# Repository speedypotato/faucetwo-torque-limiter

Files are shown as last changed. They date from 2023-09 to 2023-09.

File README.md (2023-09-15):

# faucetwo-torque-limiter
This work is licensed under a Creative Commons Attribution-NonCommercial-ShareAlike 4.0 International License.

Consumable proprietary rubber dampeners begone!  Uses a tok tleu1-618-5w torque limiter as tensioning just like a valkyrie knob assembly!

Note: This project has been fitted and tested but is still in beta.

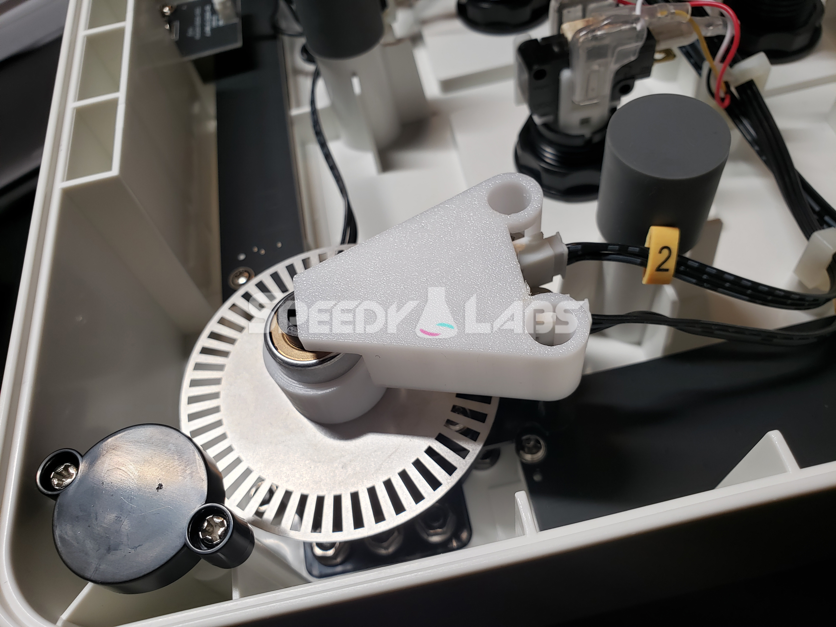
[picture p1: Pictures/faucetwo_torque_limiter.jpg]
Faucetwo Torque Limiter


This mod requires:
- 2x tok tleu1-618-5w
- 2x Part1 (3D printed)
- 2x Part2 (3D printed)
- 2x Part3 (3D printed, optional)

Video Guide:  
New: https://youtu.be/agtuq-vSzC4?si=kTFLQlY_rWy64dil  
Old(shows removal of rubber dampeners): https://youtu.be/wjkP9TPzm_8?si=DwbVowPt-fkSv-2N

Barebones guide:
1. Remove magnetic bottom cover of your faucetwo
2. (Optional if your dampeners are already worn out.  Skip to step 4.) Remove dampener and plastic support pieces.  More detail is available in Gamo2's manual https://www.gamo2.com/en/download/Faucetwo_manual_en_20210106.pdf .
3. Reassemble the knob assembly without the dampener and plastic support pieces, but don't put on the spoked wheel yet.
4. Line up the spoked wheel on the end of the shaft, then sandwich it with Part1.  Screw in the 2 M3 screws.
5. Insert the torque limiter into Part1, lining up the tabs with the slots.  It should be a fairly tight press fit.  If your tabs aren't aligned, the torque limiter will be too tall.  You can pinch the torque limiter and rotate it while it's in Part1 to adjust.
6. Unscrew the 3 screws holding the light sensor boards in place and pull out the light sensors.  Unscrew the 2 longer screws and remove the bracket.  Replace with Part3, remount with the 2 screws, and inser the boards into the slots.  Only screw in the middle screw, then proceed to the next step.
7. Unscrew the two screws holding down the two light sensors in place, leaving the middle screw alone. (if you didn't install Part3)
8. Put the screws into Part2 and line it up on top of the boards and screw it in.  Make sure to align the torque limiter slot with Part2.
9. Repeat with the second knob assembly.
10. Put the cover back on.  You're done!

## Pick up a kit or individual torque limiters here:  
https://www.speedylabs.us/product/faucetwo-torque-limiter-upgrade-kit/  
https://bluespringexpress.net/en-us/products/sound-voltex-torque-limiter-tok-tleu-618-5w

Note: The older tok tle1-618-5w is dimensionally shorter and won't work without some modifications.

P.S.
Honestly speaking, a fresh set of rubber dampeners on the faucetwo feels buttery smooth.  I was very surprised by this.  This mod still feels great in my opinion, but brings the smoothness of the knobs from a 10 down to a 9.  I think it's worth the tradeoff of never having to replace dampeners, but just thought I'd let y'all know my opinion after testing.

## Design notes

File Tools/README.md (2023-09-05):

# m4_nut_attach
This is just a tool to remove the m4 nuts if you don't have your own.  It attaches to a 1/4" hex drive.

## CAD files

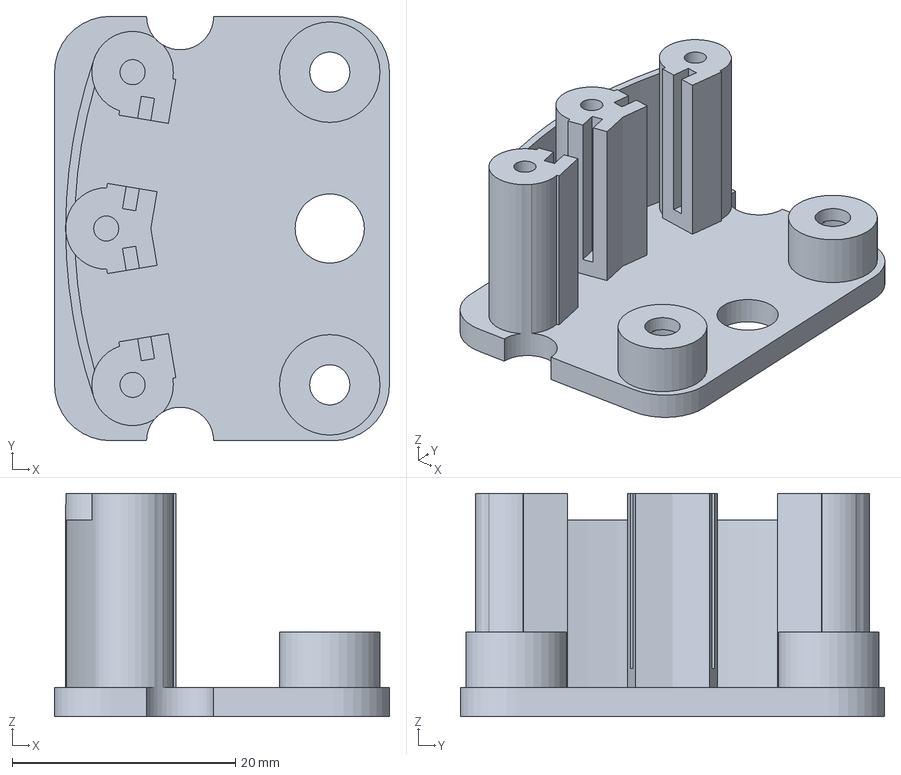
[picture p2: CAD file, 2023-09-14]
3D Prints/Part3.3MF
30.0 x 38.0 x 20.0 mm

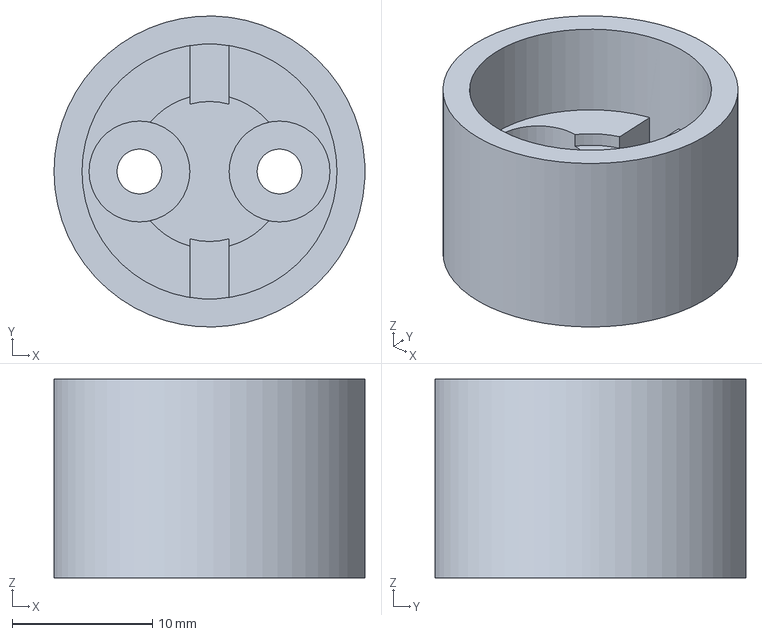
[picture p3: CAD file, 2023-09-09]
3D Prints/Part1_tle.3MF
22.2 x 22.2 x 14.2 mm

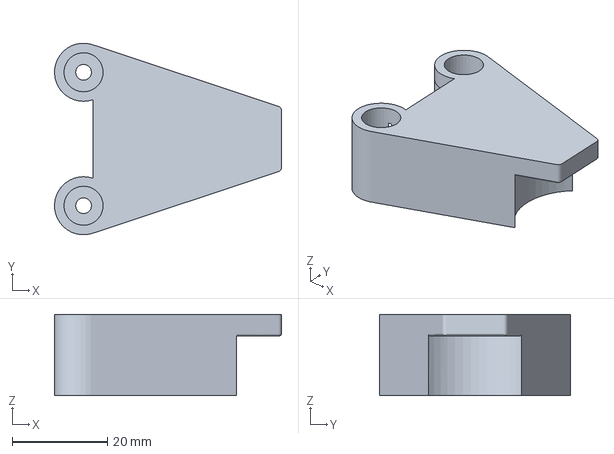
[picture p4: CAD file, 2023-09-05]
3D Prints/Part2.3MF
47.6 x 40.2 x 17.0 mm

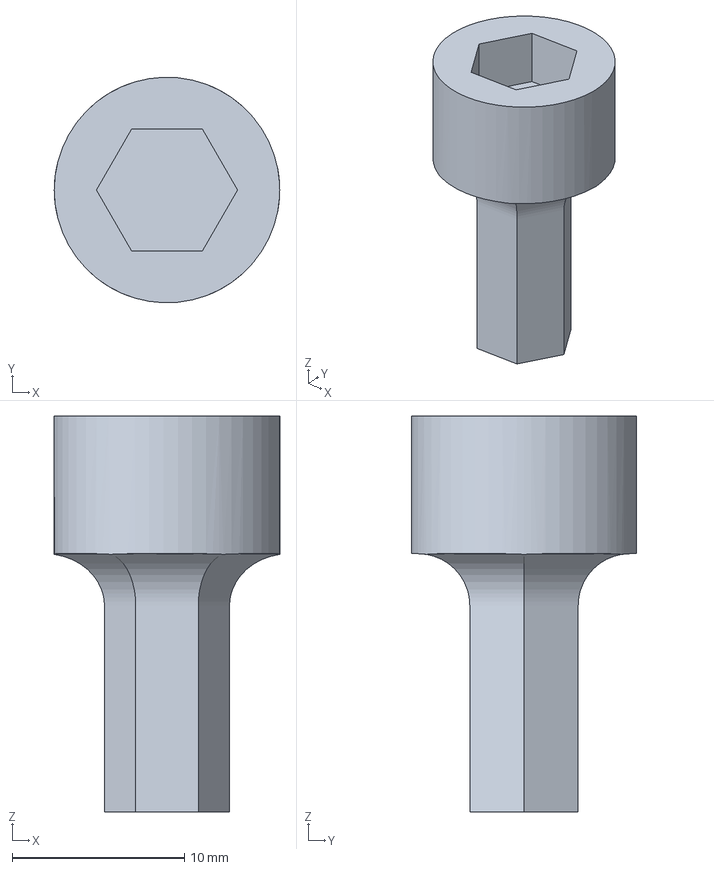
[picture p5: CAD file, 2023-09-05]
Tools/m4_nut_attach.3MF
13.1 x 13.1 x 23.0 mm

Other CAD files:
3D Prints/Part1.3MF

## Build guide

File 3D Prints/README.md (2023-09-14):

# Part1
Part1 attatches to the encoder wheel.  
Part1_tle is an UNTESTED version for the older plastic tok tle1-618-5w

# Part 2
Part2 attatches to the light sensor mount.

# Part 3 (Untested)
Part3 is a beefed up replacement of the holder for the sensors due to rare occurrences of cracking/over-tightening.

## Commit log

2023-09-05 Public release
    [Part1.3MF, Part2.3MF, m4_nut_attach.3MF]
2023-09-09 Added untested Part1_tle
    [Part1_tle.3MF]
2023-09-14 Part 3 Sensor Holder
    [Part3.3MF]
